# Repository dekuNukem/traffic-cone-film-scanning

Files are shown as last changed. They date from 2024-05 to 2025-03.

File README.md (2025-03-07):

# Traffic-Cone Film Scanning: High-Quality Digitization on the Cheap

[Discord](https://discord.gg/wB9mKjD2Cn) | [Table of Contents](#Table-of-Contents)

-----

Analog photography is having a resurgence, many people are shooting film again.

To view and share the photos, they need to be digitized.

Scanning using a digital camera is popular, but a conventional setup can cost [hundreds of dollars](images/dollaz.png).

TCFS is a low-cost 3D-printable alternative that produces high-quality results at a fraction of the price.

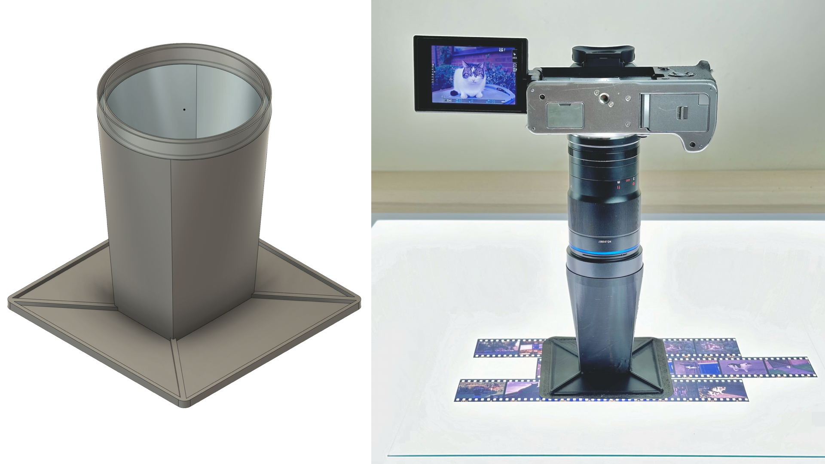
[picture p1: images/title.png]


## How It Works

* Print a cone
* Attach to macro lens
* Film under glass
* Camera point straight down.
* Focus and shoot!

## Advantages

* **Low-cost**: $1 in filaments.
* **Easy setup**:
	* No tripods/copystands
	* Fixed distance, no calibration.
* **Fully Enclosed**
	* No stray lights
	* No reflection
* **Multi-format**: Subminiature, 35mm, 120, sprockets, and more!
* **Open-source**
	* Customizable parametric design
	* CCBY4.0 license.

## Table of Contents

- [Sample Scans](#samples)
- [Items Needed](#sounds-great-im-in)
- [Cone Preparation](#cone-preparation)
- [Cone Assembly](#cone-assembly)
- [Scanning Preparation](#scanning-preparation)
- [Scanning Procedures](#scanning-procedures)
- [About Newton Rings](#a-word-on-newton-rings)
- [Feedback Wanted!](#howd-it-go)
- [License Note](#license-note)

## Samples

Fuji XT4 + Laowa 65mm f/2.8

35mm



35mm Sprocket



6x6 Negative



6x6 Slide

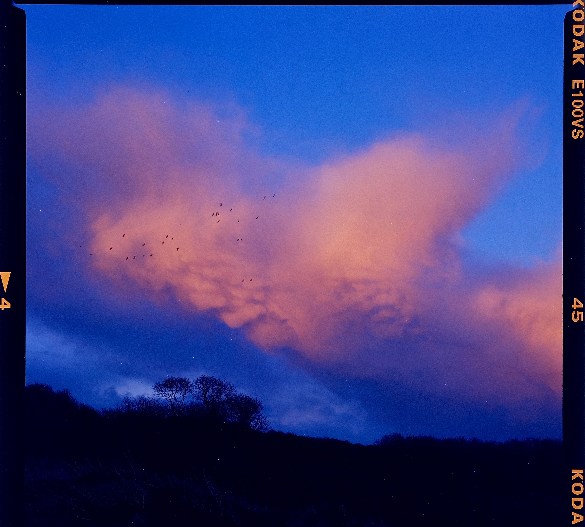
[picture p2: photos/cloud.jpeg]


[More full-size samples here](https://github.com/dekuNukem/traffic-cone-film-scanning/tree/master/sample_scans)

## So What's the Catch?

While TCFS can achieve excellent results, there are a few things to keep in mind.

#### DIY Involved

* You need to be a bit handy.
* Wire a plug, use a caliper, etc. Nothing too crazy.

#### Obtaining a Cone

* One cone per film format.
* For lowest cost, print your own. Basic 3D printing experience needed.

#### No Magic Bullet

* TCFS can be as good as any expensive DSLR/mirrorless setup when done properly.
	* Able to get the most out of 35mm & smaller
	* Also great with medium format
	* But likely won't extract all its resolution
* For utmost quality, wet mounting/drum scans are still hard to beat.
* Main advantage is excellent scans at much lower cost, easy setup, and faster speed.

## Sounds Great, I'm In!

Let's get started! The setup involves:

* Digital Camera
* Macro Lens
* Lens Hood
* Light Table
* Flat Glass
* The Cone

## Digital Camera

Obviously, you need one of those.

Any DSLR or Mirrorless made in the past decade should be more than good enough.

No need for latest and greatest. APS-C sensor is plenty.

A **swivel / tilt screen** would be nice to have, makes checking focus easier.

## Macro Lens

The quality of the scan depend largely on the lens.

For best results, I recommend:

* A proper **macro lens**
* With **internal focusing** (front element doesn't move)

---------

**Magnification Ratio** is important:

* A 1:1 (1x) ratio means the lens can project the **actual size of the subject** onto the sensor
* At 2:1 (2x), the subject can be projected **twice as big** on the sensor
* Therefore, a decent MR is useful for smaller formats (35mm and under).

-------

You can drop 4 figures on a flagship first-party lens, but for film scanning it's a bit overkill.

A popular choice is [Laowa 65mm f/2.8 2x Ultra Macro APO](https://www.venuslens.net/product/laowa-65mm-f-2-8-2x-ultra-macro-apo/):

* 2x MR
* Superb image quality
* Around $330

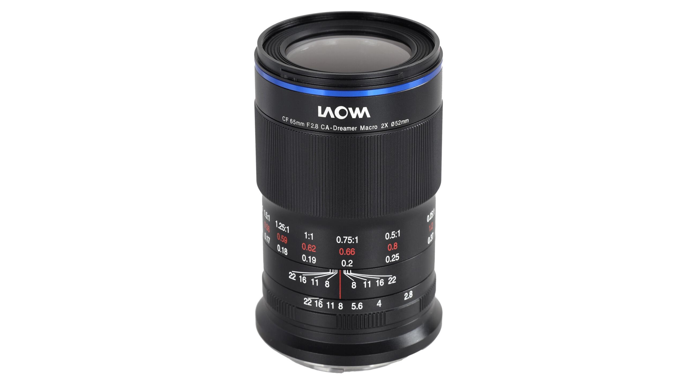
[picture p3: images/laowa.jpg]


Another one is [7Artisans 60mm f/2.8 Mark II](https://7artisans.store/products/7artisans-60mm-f2-8-mark-ii-macro-lens-for-sony-e-fuji-fx-canon-eos-m-olympus-m43-nikon-z-mirrorless-cameras):

* 1x MR
* Excellent image quality
* Around $160

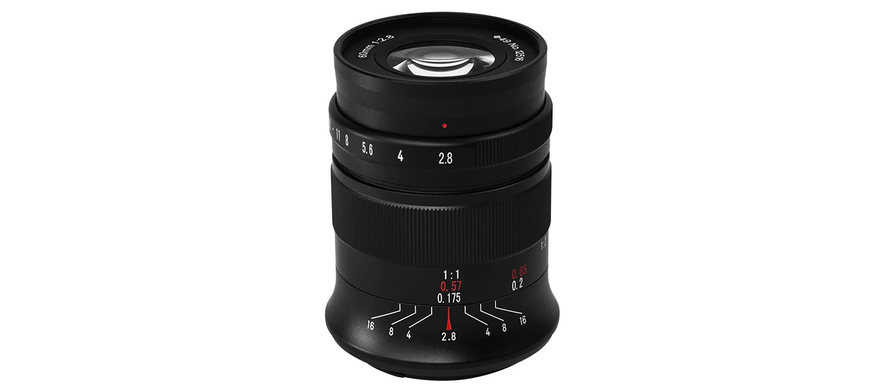
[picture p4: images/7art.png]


I have both, and personally I prefer the Laowa:

* Inboard aperture ring, less likely to bump into during focusing.

* Smoother focus ring, allowing finer adjustments.

* Extra magnification handy for subminiature formats (110, 126, half-frame, etc)

Anyway, can't go wrong with either. Available cheaper on aliexpress.

-----------------

Many **vintage lenses** are good candidates too, and can be even cheaper.

However, you need to do your own homework. Search `Film scan macro lens` on google.

[This article has a fairly extensive tier list](https://web.archive.org/web/20240206003914/https://www.pixl-latr.com/how-good-a-macro-lens-do-you-really-need-for-dslr-mirrorless-camera-scanning/).

## Lens Hood

We need a lens hood to attach the cone to.

* **Circular** shape
* **Fully enclosed**
* One-piece **metal** (not collapsible)
* Not too tall

Just get the cheapest from ebay or aliexpress, they are all the same. 

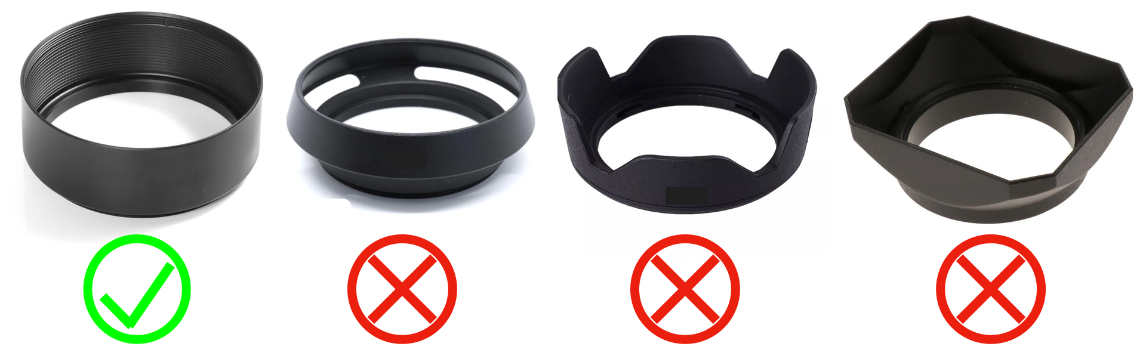
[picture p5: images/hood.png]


## Light Table

A bright and even light source is needed to illuminate the film from behind.

You can spend a lot on the usual suspects that sponsor Youtube videos.

Instead, I recommend getting a **LED Light Panel** for office ceilings.

They are a lot cheaper, and give you a massive area to work with.

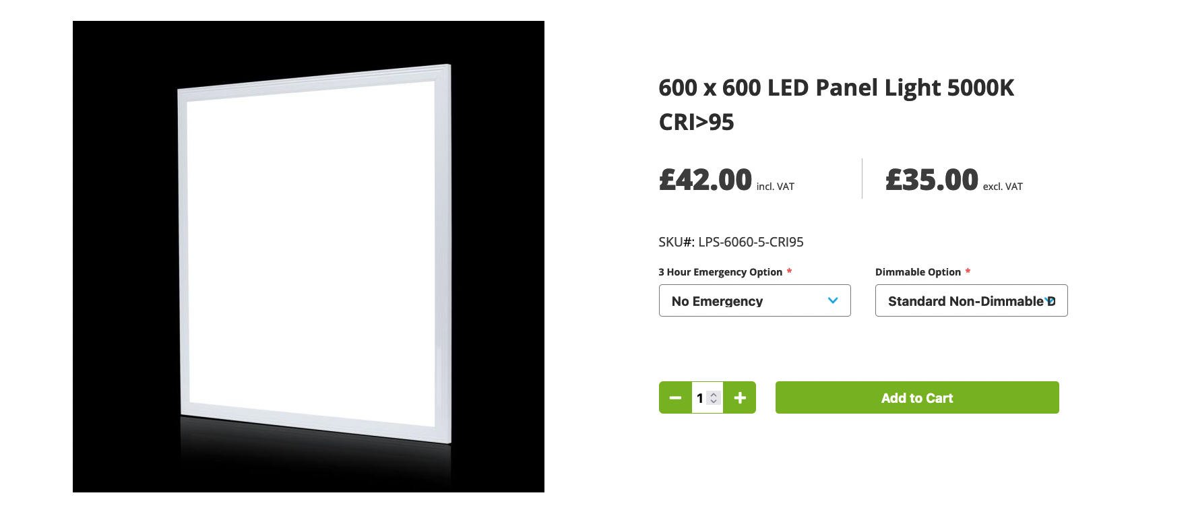
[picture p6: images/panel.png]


* Make sure it's **High-CRI** (>95)
* Neutral color temperature (**Around 5000K**)
* Flat matte surface finish (pretty sure they all are)
* Standard size is 600x600mm / 24x24in 
* Smaller ones available, but I like it big!

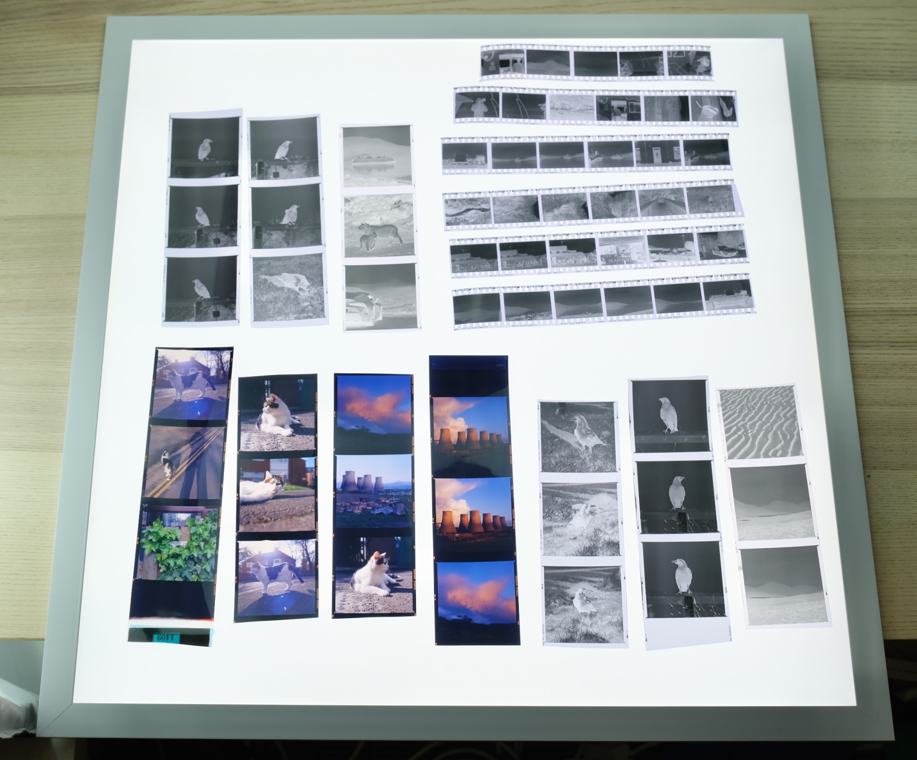
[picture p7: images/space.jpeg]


The LED panel comes with a power adapter. You need to wire a plug to it.

⚠️ ⚡ Mains voltage is involved! 

⚠️ ⚡ Make sure you know what you're doing!

⚠️ ⚡ Look up how to wire a plug in your country.

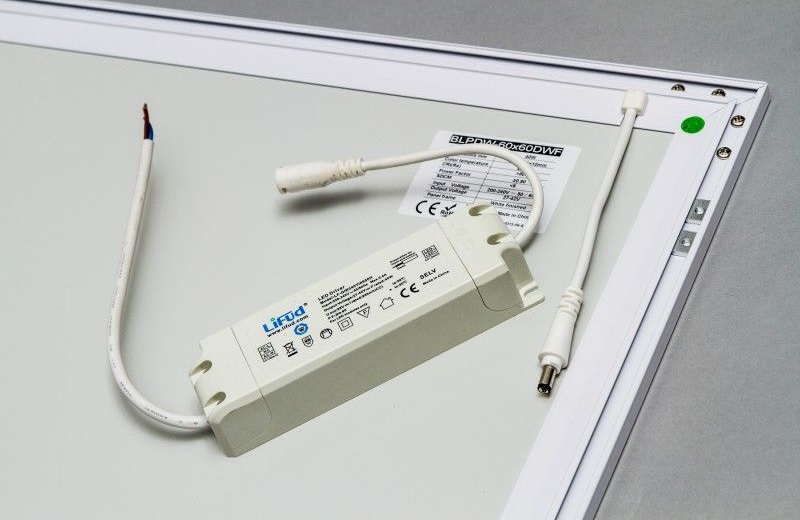
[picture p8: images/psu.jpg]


Generally:

* Brown is **LIVE**
* Blue is **NEUTRAL**
* Green/Yellow is **EARTH**

Inexpensive lever-actuated connectors like WAGO 221 is very useful.

If you do use them, make sure to have **strain relief**, so it won't accidentally pull out and expose the live wire.

Just a simple knot should be fine. When tugged, it will pull the knot tighter instead of ripping out the wires.

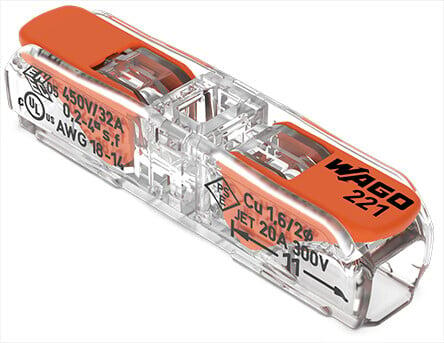
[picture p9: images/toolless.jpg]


You can use a regular plug and turn it on/off at the power strip, or an inline switch to be extra fancy.

Remember to **twist-lock** the output jack!

## Flat Glass

We need a piece of glass to hold the film flat on the light table.

* Around 2mm thickness
* At least 8x10 in size, mine is 11x14.
* Make sure it's **glass** NOT acrylic
* I got mine from a picture frame at a thrift store

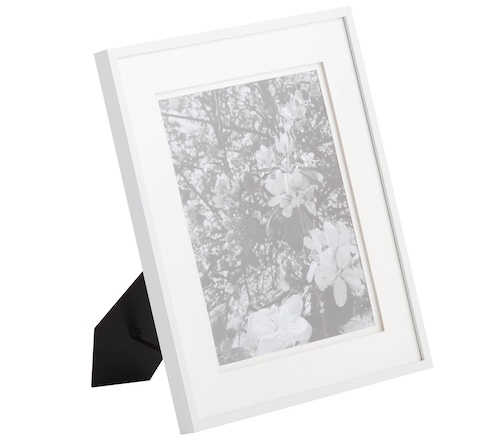
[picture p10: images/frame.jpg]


#### But what about newton rings???????

I'll talk about it later, but just know it won't be a big problem.

I suggest start with cheap plain glass, you can always upgrade to ANR glass later.

## Cone Preparation

For best results, the cone should be customized to your specific lens.

### I have the lens below!

* `Laowa 65mm f/2.8 2x Ultra Macro APO`
* `7Artisans 60mm f/2.8 MK II`

Great! Download a file and go to the next section.

* [35mm Full Frame](3d_models/laowa_7art_35mm_fullframe.stl?raw=true)
* [35mm Sprocket](3d_models/laowa_7art_35mm_sprocket_6x6.stl?raw=true) (using 120 adaptor on 6x6 camera)
* [645](3d_models/laowa_7art_645.stl?raw=true)
* [6x6](3d_models/laowa_7art_6x6.stl?raw=true)
* [6x7](3d_models/laowa_7art_6x7.stl?raw=true)
* [6x9](3d_models/laowa_7art_6x9.stl?raw=true)

### I'm using my own lens / I want to customize!

[Click me to learn how to customize your cone.](cone_customization.md)

## Printing the Cone

Now you have the model, time to print it!

If you don't have a 3D printer, try local library, makerspace, or online printing services.

* Use **opaque black** filament, PLA works just fine.
* Around 10-20% infill
* Very simple design, turn up the speed if you want.

2 hours later, voilà:

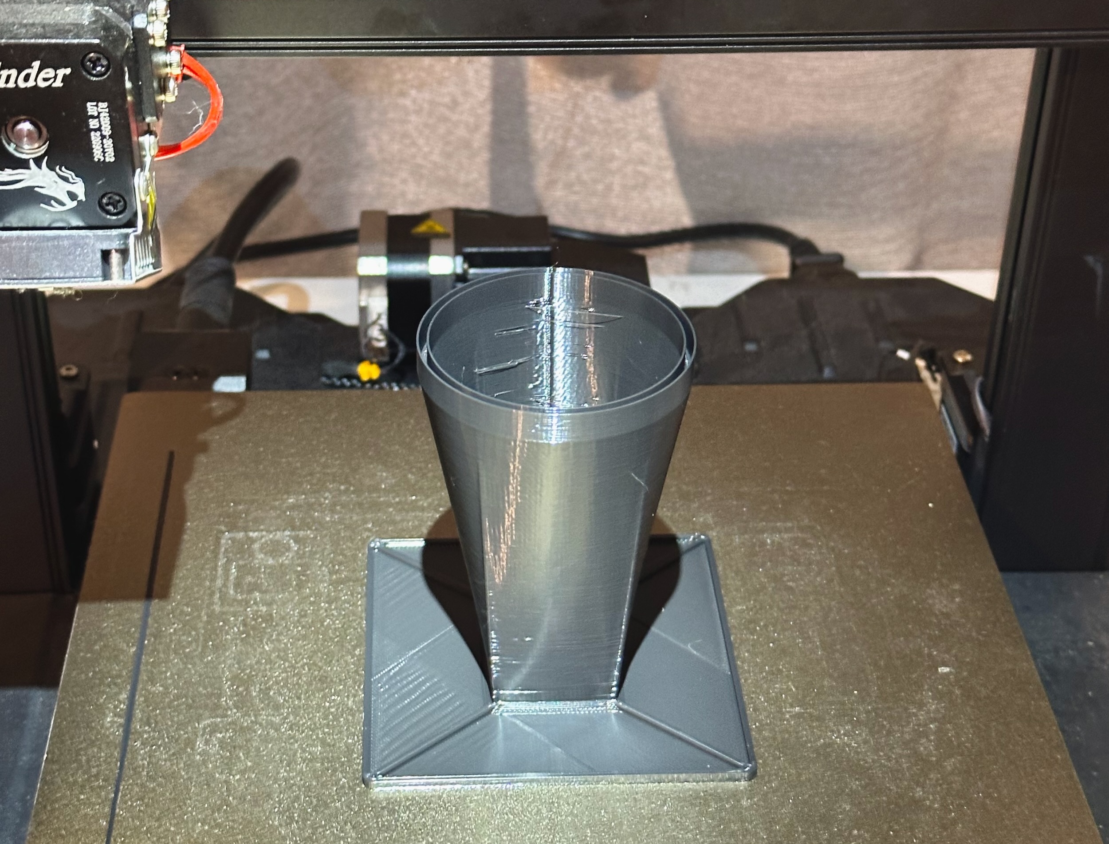
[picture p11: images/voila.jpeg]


* Wait for the bed to cool down before removing.
* Double check the base is **completely flat**.
* It **must not** wobble when placed on flat surface.
* If warped, improve bed adhesion. Re-level, hairspray, raft, etc.

## Cone Assembly

* First, remove any filament whiskers/strands **near the film gate**.

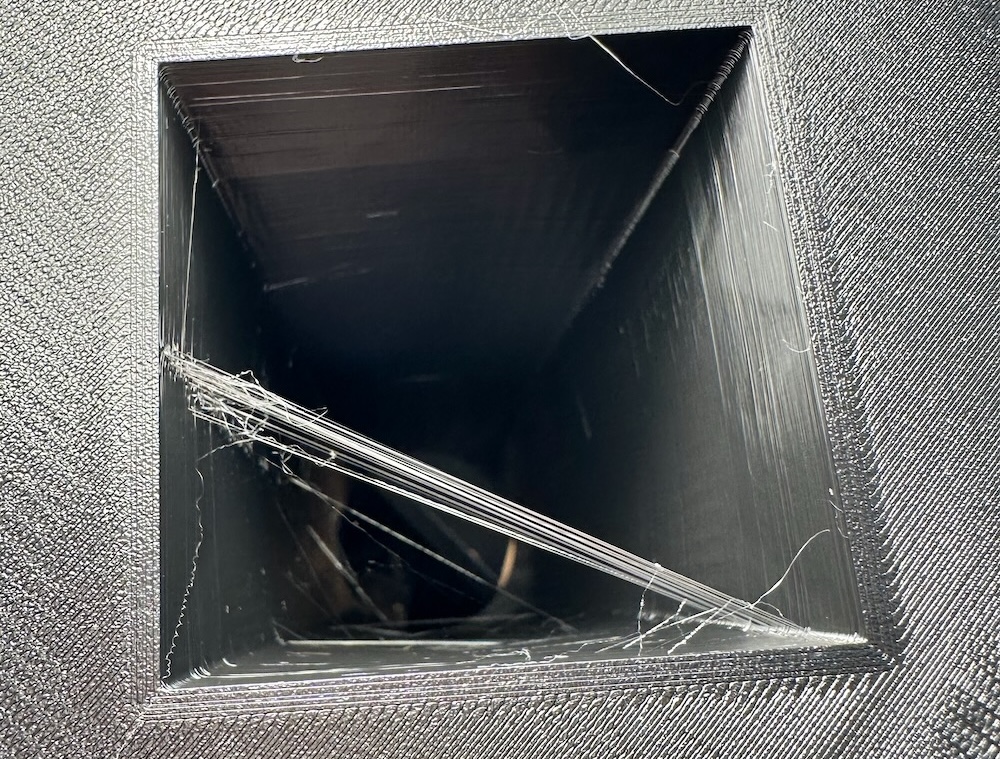
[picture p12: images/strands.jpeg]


* Whiskers higher up won't show up, leave them if you want.

-----

* Put the cone on the light table
* Attach the lens hood, moderately tight

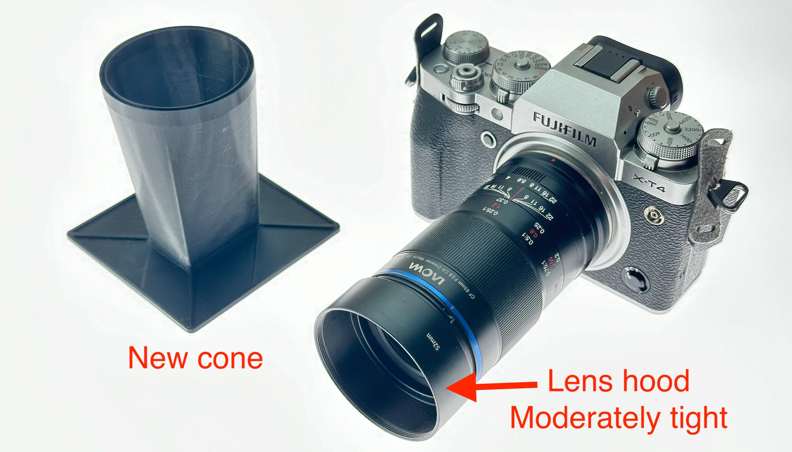
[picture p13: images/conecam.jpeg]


* Hover the camera just over the cone, barely touching.
* Adjust focus and position.
* Until the film gate is **parallel** with camera frame

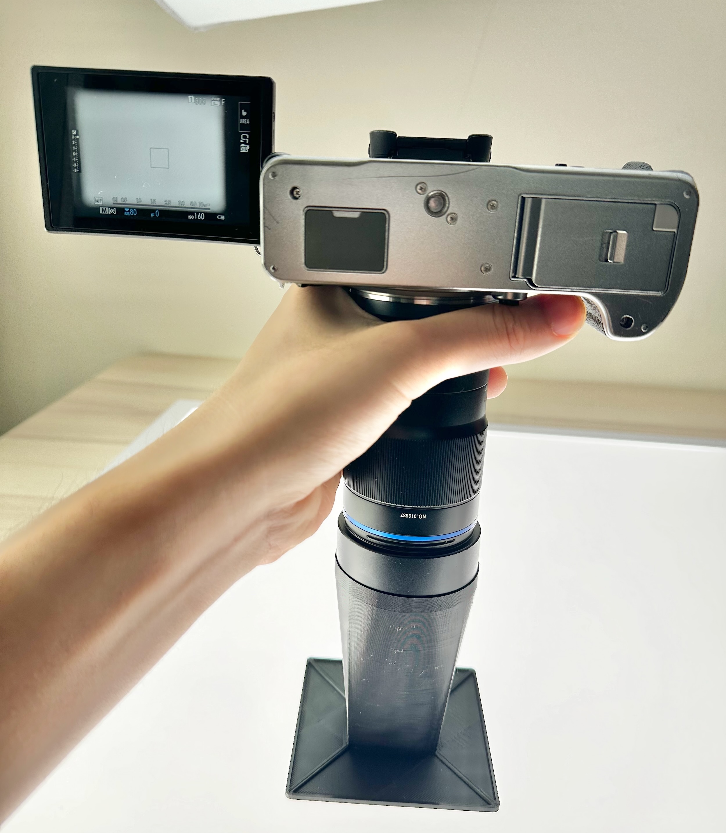
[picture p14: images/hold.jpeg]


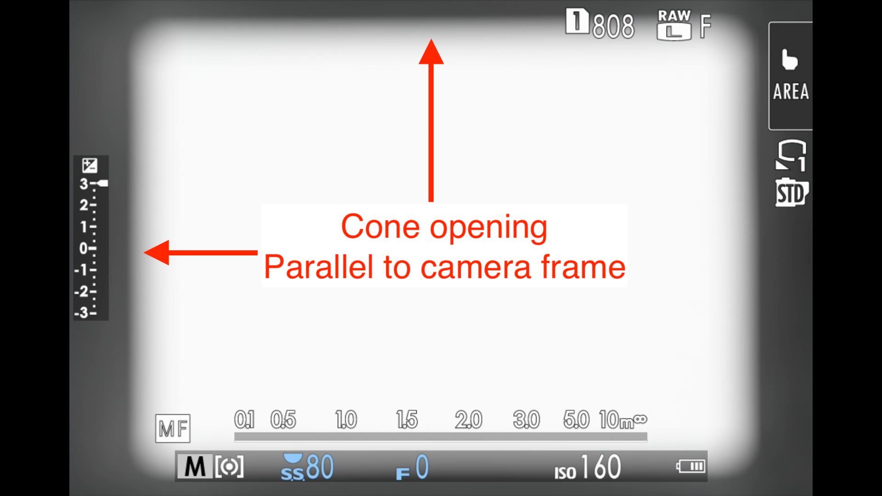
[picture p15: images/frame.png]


* Mark the position of the cone with paint marker, or a scratch mark.

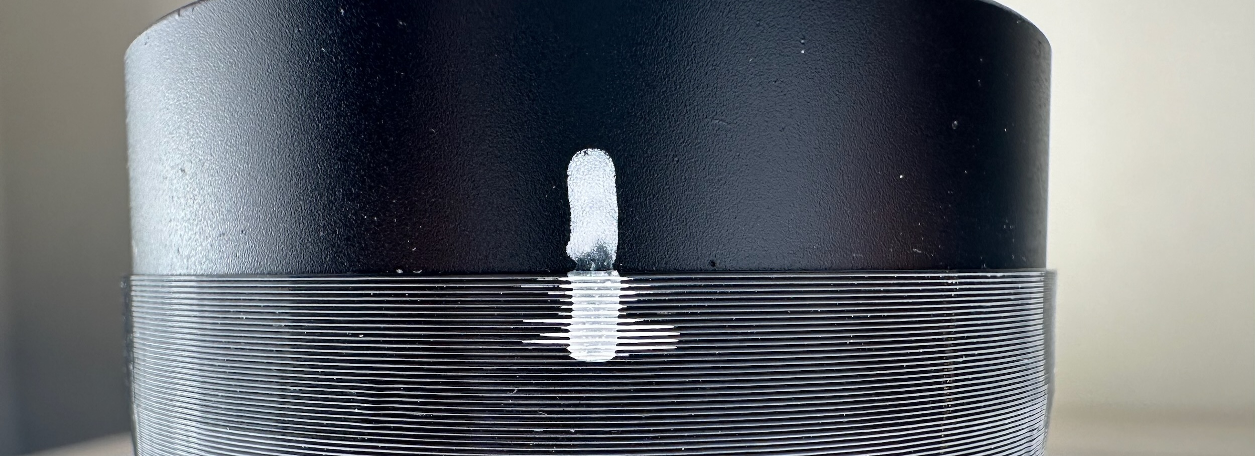
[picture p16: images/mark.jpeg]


* Unscrew the lens hood
* Put the cone on a flat surface (**NOT LIGHT TABLE**)
* Ensure the mark is still aligned
* Push all the way in
* Make sure it **bottoms out** and **flat and level**

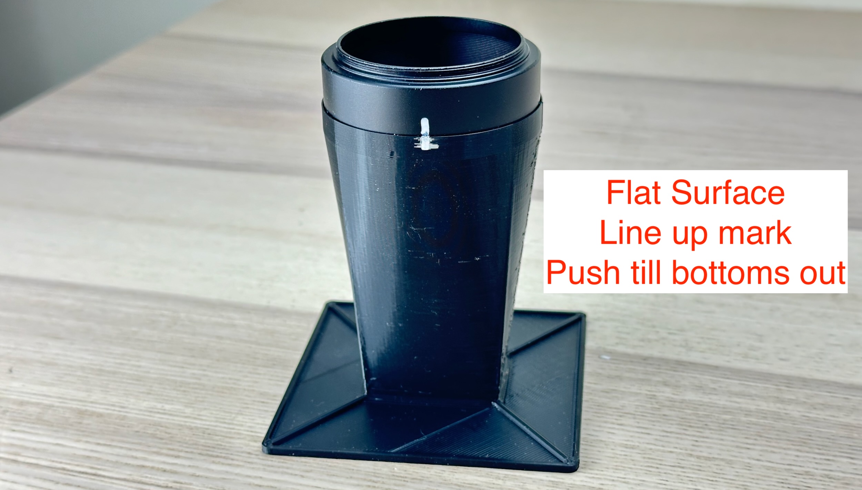
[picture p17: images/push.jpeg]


The cone should grip the lens hood tightly. 

If too loose, use some duct tape, or print a new one.

## Scanning Preparation

The cone is ready! Before start scanning, we need to set up a few things.

### Light Panel

Put the light table on a flat surface.

If the power jack sticks out, let it hang off the edge. Double check it is **twist-locked**.

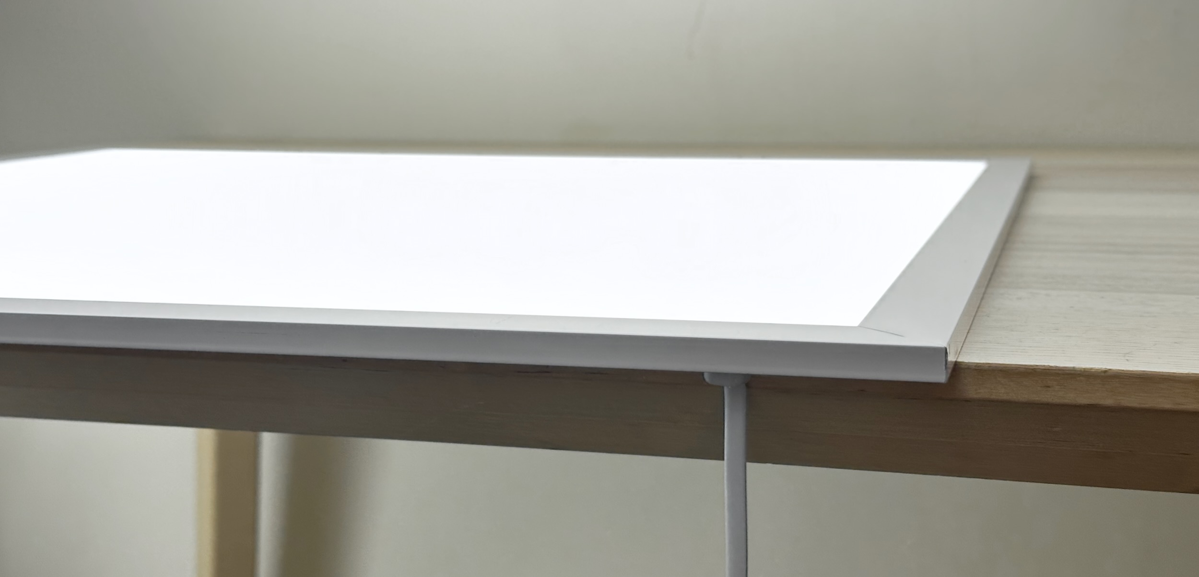
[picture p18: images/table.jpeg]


The panel should be flat and not wobble.

### White Balance

Set a **custom white balance** to your light table.

Usually involves taking a picture of the blank table. Refer to user manual.

### RAW Output

Select RAW output format for best quality, needed for most converting software.

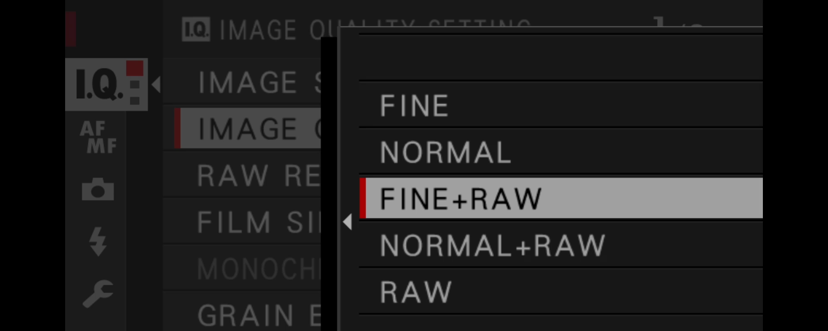
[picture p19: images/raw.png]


### Focus Assist

We are going to manually focus on the negative.

**Focus peaking** is essential to ensure a sharp scan.

Make sure it's on.

Color blue has good contrast against orange negatives.

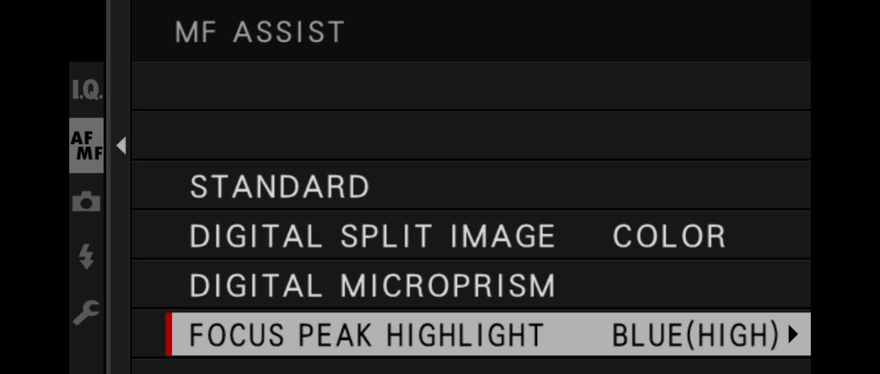
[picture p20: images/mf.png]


### Dust Management

We have a few potential surfaces for dust, so it is crucial to be as clean as possible.

#### WEAR GLOVES

* **DO NOT** touch film / glass with bare hands!
* I use disposable gloves, make sure its **powder-free**.
* Reusable gloves works too, but may shed lint.

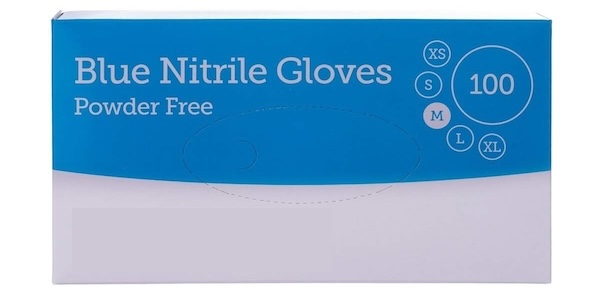
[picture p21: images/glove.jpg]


#### Wipe-down

* Before a scanning session, wipe clean the light table and glass (both sides).
* I use **Chamois Leather**. They are inexpensive, but make sure it's real (as in from an animal).
* Microfibre cloths works too, but I find them shed a lot of lint. 

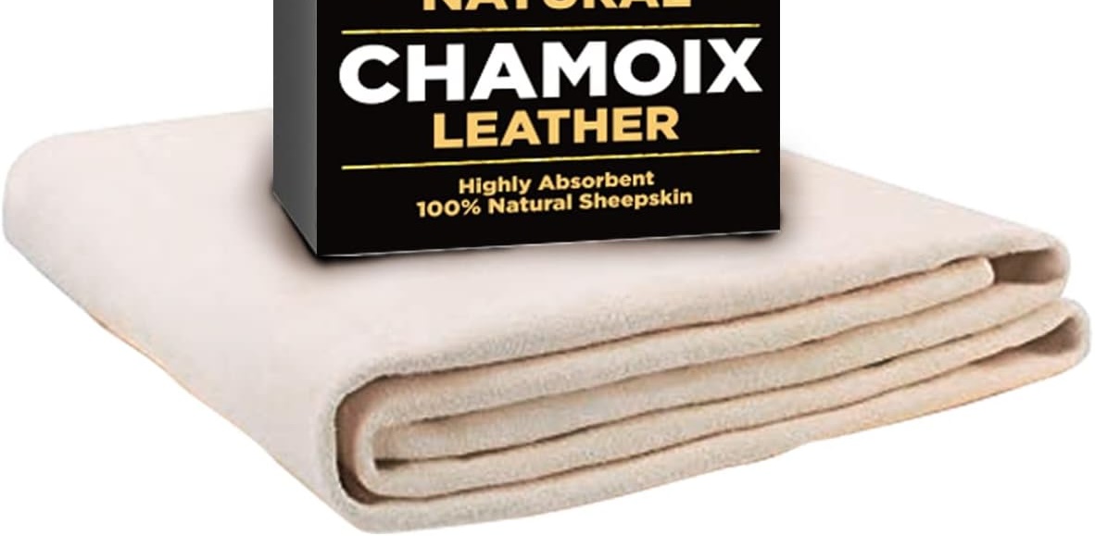
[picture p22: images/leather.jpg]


## Scanning Procedures

Finally! Let's start.

* **Wear gloves**

* Wipe down the glass and light table with chamois leather

* Place film strips **emulsion side up**

	* The side that **curls up**

	* Picture/edge markings should **look mirrored**

	* Place near the **CENTER** of the light table

	* Can be the entire roll if your glass is big enough

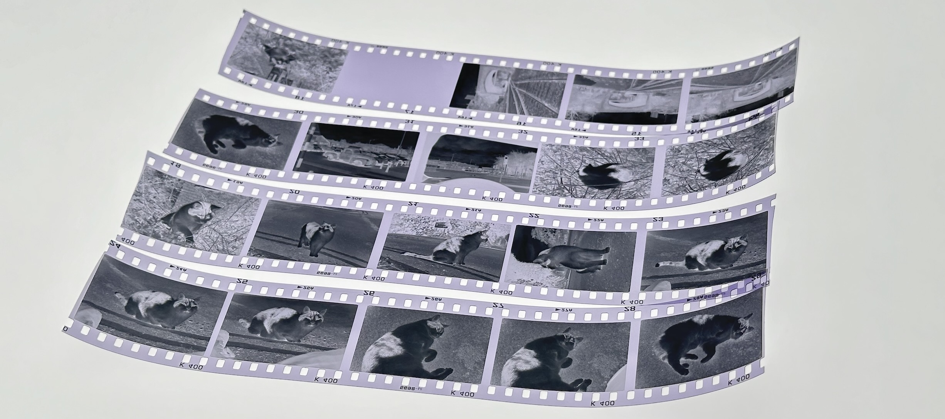
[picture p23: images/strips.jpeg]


* Glass on top. Ensure **no overlapping**

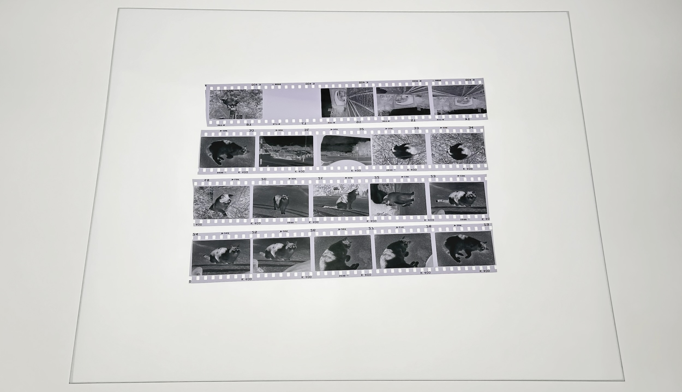
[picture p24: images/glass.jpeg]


* Double check camera settings:
	* Custom white balance
	* RAW output
	* Manual focus w/ **focus peaking**
	* Lowest ISO

* Set aperture to f/8
	* Too small aperture (large f number) would soften the image due to diffraction 
	* Too large aperture (small f number) makes it difficult to focus
	* f/8 is just about right

* Use **center-weighted autoexposure**. Or fully manual if you want.

* Using a **remote release** is strongly recommended to reduce vibration and speed up the process

	* The type with 2.5mm jack are all the same, just get the cheapest one
	* You camera might also support wireless remote or phone app

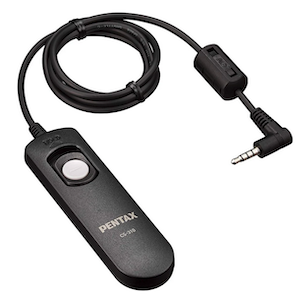
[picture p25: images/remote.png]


---------

* Attach cone to the camera

* Place over a negative

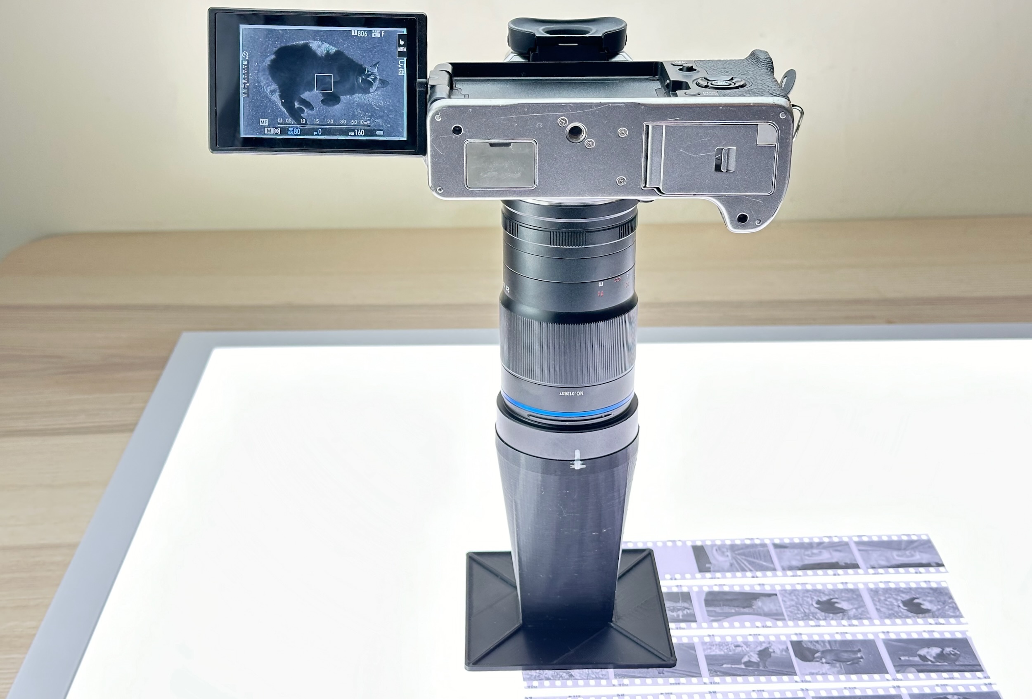
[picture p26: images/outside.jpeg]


* Line up the picture

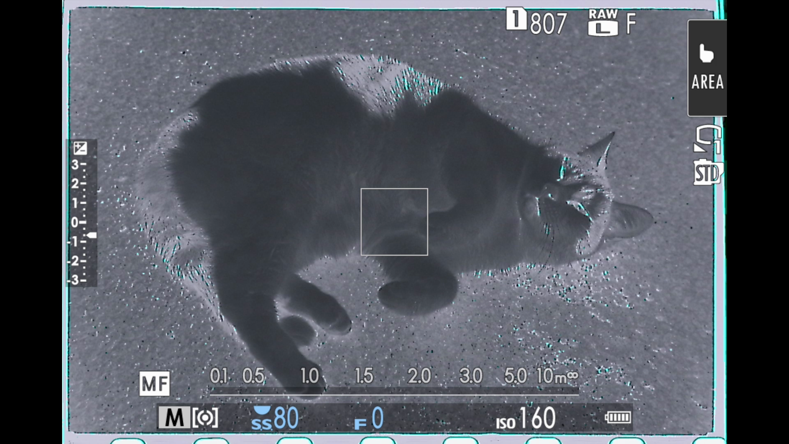
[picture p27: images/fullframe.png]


* Enter **magnified view** with focus peaking

* On Fuji X-T4, push the rear thumbwheel. Look up how to do it on yours.

* Find a sharp area on the negative

* Adjust focus ring. **Try not to apply too much downward pressure**.

* Until you achieve **maximum amount of "sparkles"**



* The tolerance is razor-thin! Tiny amount of movement is all you need.

-----

Now we are in focus!

From now on, avoid touching the camera as much as possible!

* Take a photo using remote release / remote app / self timer.

* Slide the cone around the glass for each frame

* Grab the neck of the cone, not the lens, to avoid accidentally knocking out focus.

--------

It should stay in focus for the whole session.

If you're paranoid, re-focus every time you lift the glass to put new negative in.

Definitely re-focus if left overnight. Temperature changes can cause focus drift.

## Post-Processing

Now we have high-quality scans in RAW format.

Additional processing is needed to get the final result.

We need to **invert**, **mirror**, and adjust the color of the photo.



There are a lot of guides online, so I'm not going to cover the details.

For black and white, I find it doable manually. But for color, it's much easier with a dedicated software.

Popular ones include:

* [Negative Lab Pro](https://www.negativelabpro.com/) (paid, requires Adobe Lightroom)

* [Grain2Pixel](https://grain2pixel.com) (free, requires Adobe Photoshop)

* [Darktable + Negadoctor](https://docs.darktable.org/usermanual/3.8/en/module-reference/processing-modules/negadoctor/) (free, but very fiddly last time I tried)

* [Filmomat SmartConvert](https://www.filmomat.eu/smartconvert) (paid, standalone)

-------

Personally, I use Filmomat SmartConvert to invert the negative, and macOS photos app for minor adjustments.

Zeiss Ikon Contessa 35 (Folding, 533/24), c. 1952.



Amazing how good it looks despite being over 70 years old!

## Key Points

As always, you'll get quicker with time.

To recap, those are the most important points to remember:

* **Wear gloves**
* Chamois leather wipe-down
* Emulsion side up
* White balance / RAW output / Low ISO
* f/8
* Nail the focus
* Use remote release

## A Word on Newton Rings

Newton rings are circular interference patterns caused by close proximity of two smooth surfaces.

They often appear where film touches smooth glass:

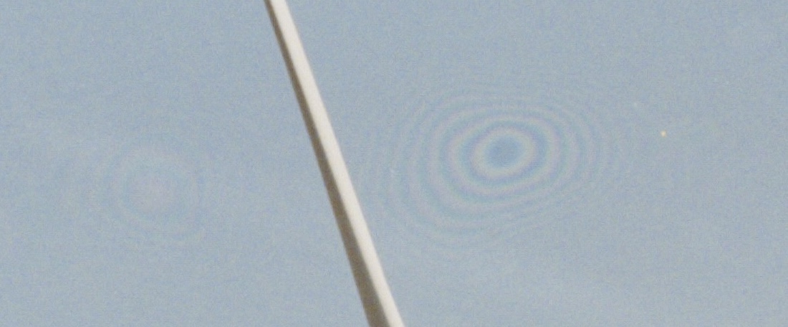
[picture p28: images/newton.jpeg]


Curiously, from my experience, it almost never occurs with TCFS, even with plain glass.

I have a theory:

* We scan with emulsion side up, which is typically more matte.
* Film are also placed near the center of the light table.
* Due to its size, there might be a minuscule amount of curvature on its surface.
* Such that the film are not squished right against the glass!

#### 😡 OMG that means the film is NOT FLAT!!1!🤬y didnt u tell me eariler what a waste of time!! 

* The curvature (if any) is absolutely tiny, especially with the camera pushing down.
* Such curvature is well within the depth of field of your digital camera.
	* For 35mm, you have [2.6mm DoF](images/dof35mm.png).
	* That's the thickness of 4 credit cards, or 20 times thicker than the film itself!
	* You'll definitely notice if it's that much.
	* For 120, [DoF is 7.6mm](images/dof120.png). More than a quarter inch!

---------

* I would suggest:
	* Follow the instructions
	* Focus properly on the negative
	* Look at the result yourself and decide. The proof is in the pudding. 
* Feel free to examine my [full-size samples](https://github.com/dekuNukem/traffic-cone-film-scanning/tree/master/sample_scans).
* Finally, if it really bothers you, you can always get some ANR glass.
* [Useful discussion here](https://old.reddit.com/r/AnalogCommunity/comments/pex269/anr_glass_alternative_using_etched_frame_glass/).

## How'd It Go?

That's it! If you read this far, hopefully you have already made some scans, or at least interested in trying!

I would love to hear about your experience, good or bad, as well as any comments, questions, and suggestions, in order to improve this process.

Get in touch [via Discord](https://discord.gg/wB9mKjD2Cn), or email: dekuNukem&gmail.com!

## License Note

The **scanning cone** design is under [CC BY 4.0 License](https://creativecommons.org/licenses/by/4.0/deed.en)

You can:

* Share, modify, remix, and redistribute the material, even commercially.
* **AS LONG AS** you give appropriate credit to me (dekuNukem) and [the project page](https://github.com/dekuNukem/traffic-cone-film-scanning).

The sample photos are **NOT** under CC BY 4.0 and are all rights reserved.

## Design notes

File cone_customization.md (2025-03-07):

# Traffic-Cone Film Scanning: Customization Guide

[Main Page](README.md) | [Discord](https://discord.gg/wB9mKjD2Cn)

----------

This guide shows you how to customize the cone to **your particular lens and film size**.

## Install Autodesk Fusion

Autodesk Fusion is a popular 3D CAD software.

We're going to install the free version, customize the traffic cone, and print the result.

------

Go to this link:

https://www.autodesk.com/products/fusion-360/personal

Create a free personal-use account, download, and install.

* Launch Autodesk Fusion
* Click through until you see the main screen
* File icon -> Open...

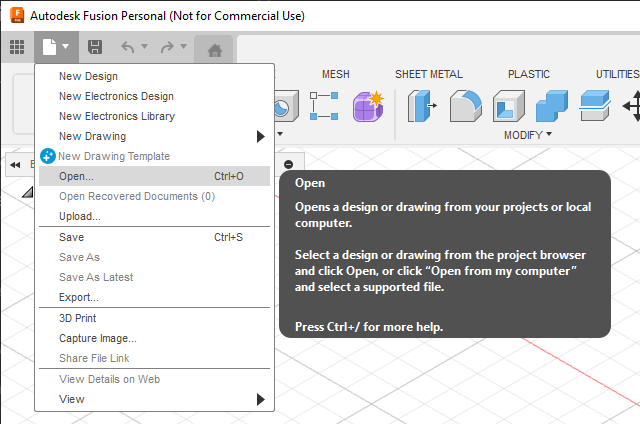
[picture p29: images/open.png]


* Select `Open from my computer...`

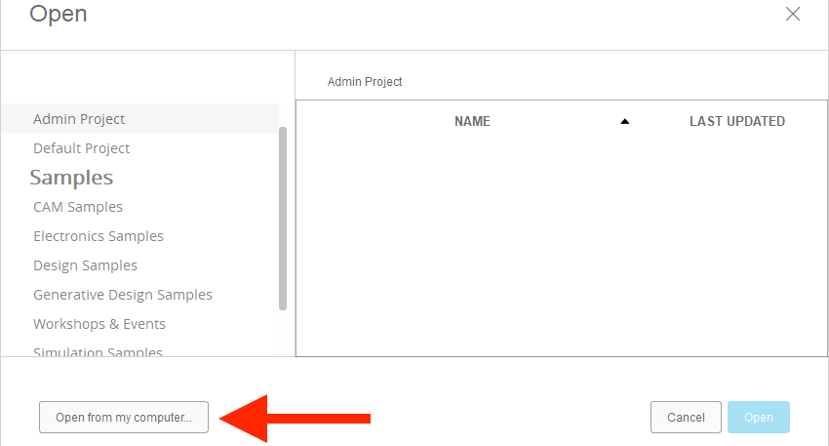
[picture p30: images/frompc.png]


* Download the [template cone](https://github.com/dekuNukem/traffic-cone-film-scanning/raw/master/3d_models/cone_template.f3d) and select it.
* Feel free to drag the viewcube to look around.
* Click its edge/corner/face to snap to view point.

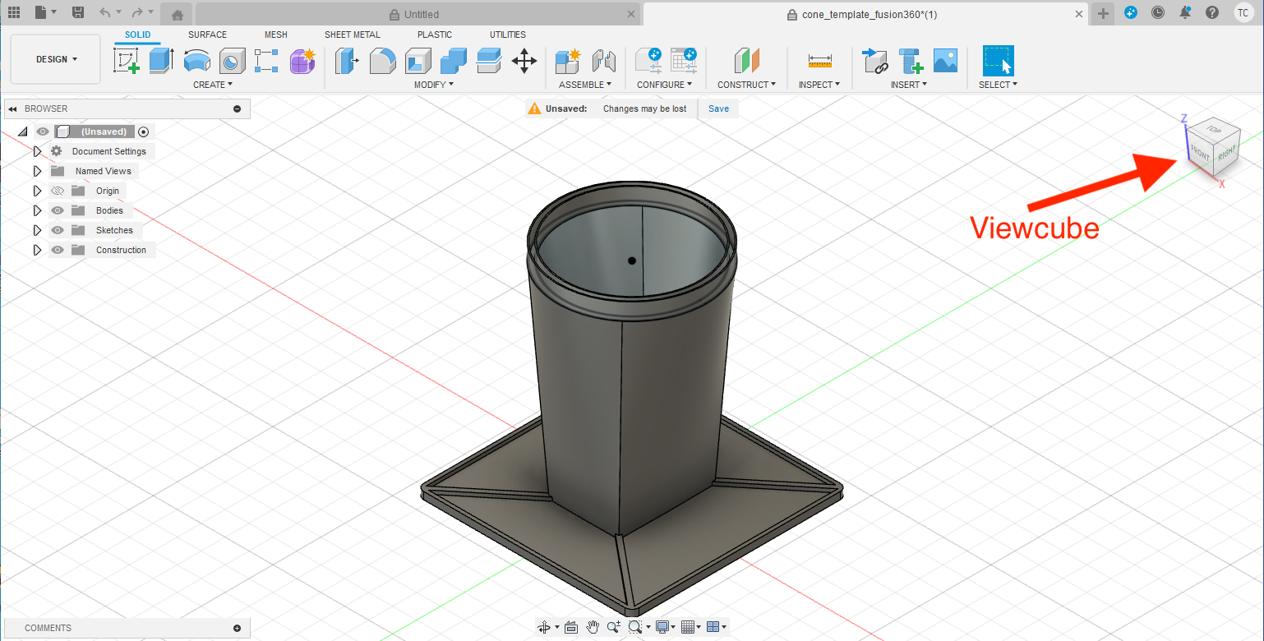
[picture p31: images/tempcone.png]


* Click on `MODIFY` menu
* Select `Change Parameters`

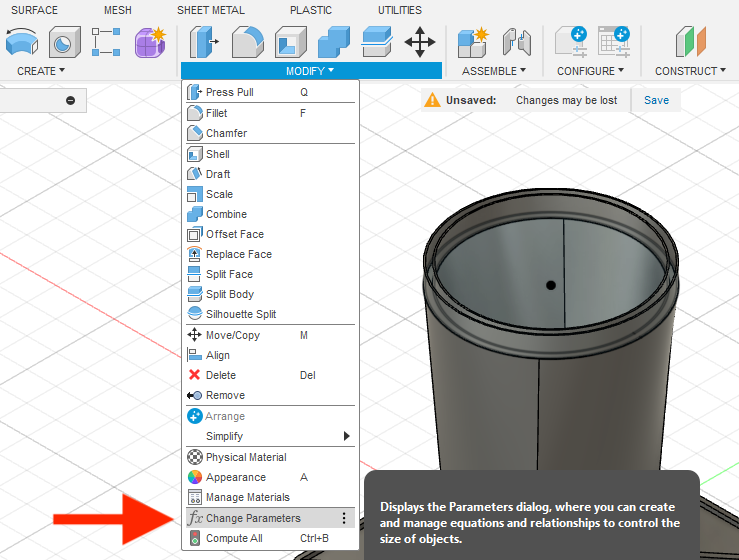
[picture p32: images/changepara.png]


* Here you can see all the parameters for this cone.

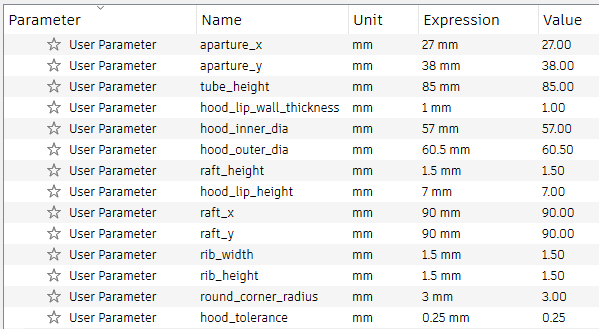
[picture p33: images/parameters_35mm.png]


* Don't touch anything yet!
* Changing the values here will alter how the cone looks. 
* But first, we need to do some measurements.

## Measurements

In this example, I want to make a cone for **645** format with `Laowa 65mm f/2.8` and `Fuji X-T4`.

* Light panel flat on table, turn on.
* Film under glass
* Don't worry about dust yet, it's only for measurement.
* Install lens hood

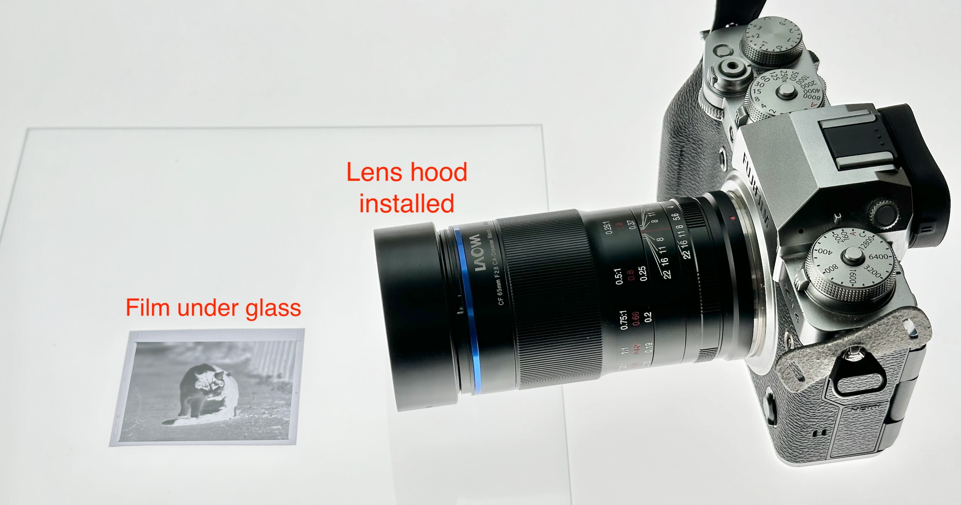
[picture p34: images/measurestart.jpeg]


* Camera on
* Point straight down
* As best as you can, adjust height and focus, until the photo:
	* Fills most of the frame, AND
	* In focus
* Leave a little space near the edge to make alignment easier 

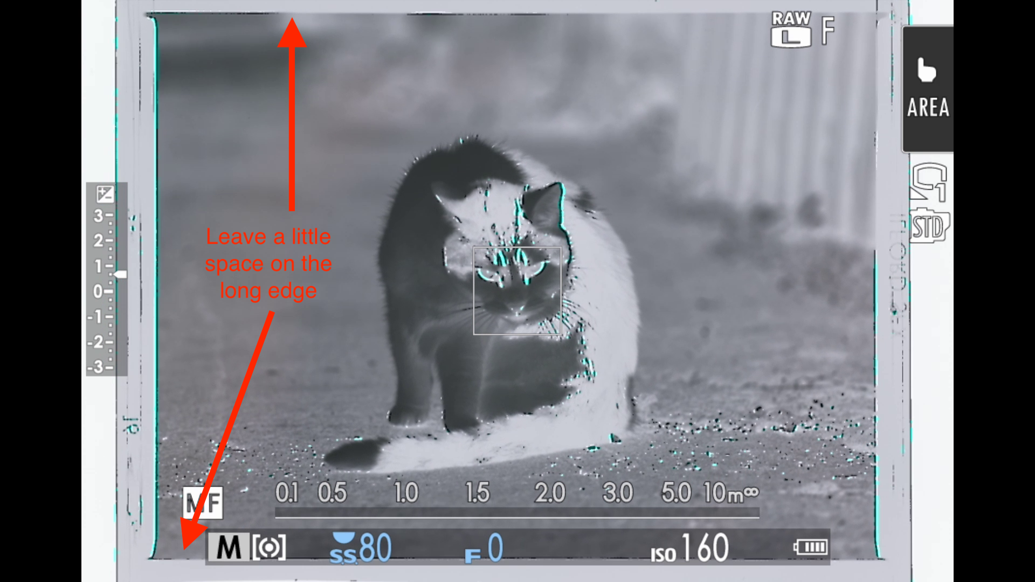
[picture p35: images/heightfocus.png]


* Hold steady
* Measure the distance from **`glass surface`** to **`lip of lens hood`** in **mm**

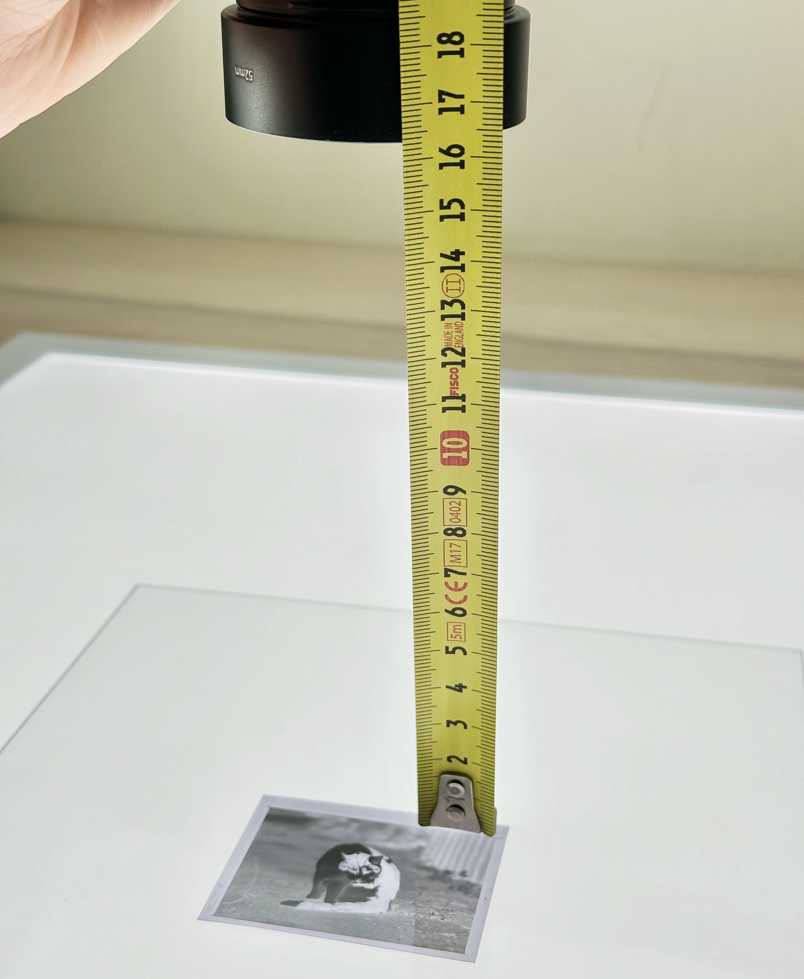
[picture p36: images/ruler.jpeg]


This will be the **height** of the cone.

Around 16cm, or 160mm, in this case.

Write it down.

----

Next, use a caliper, measure the **inner** and **outer diameter** of the **outward facing rim** of the lens hood in **mm**.

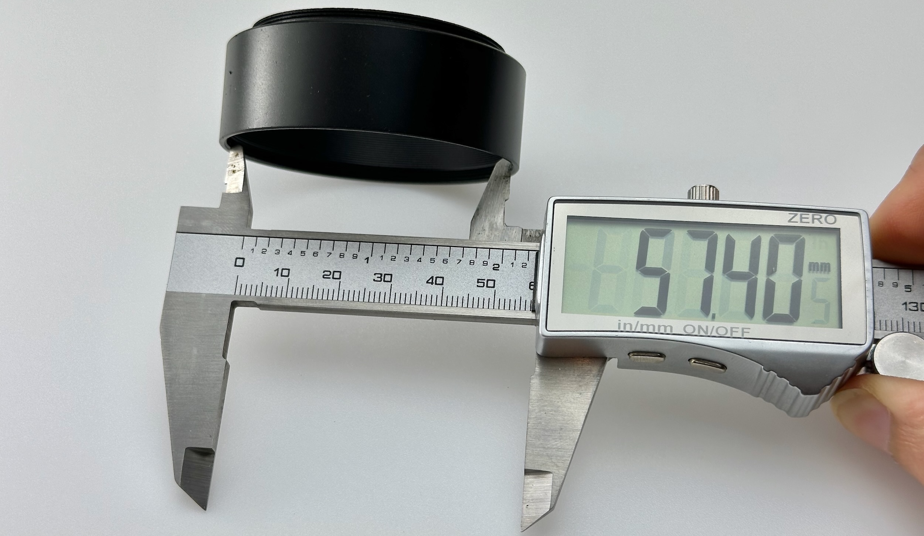
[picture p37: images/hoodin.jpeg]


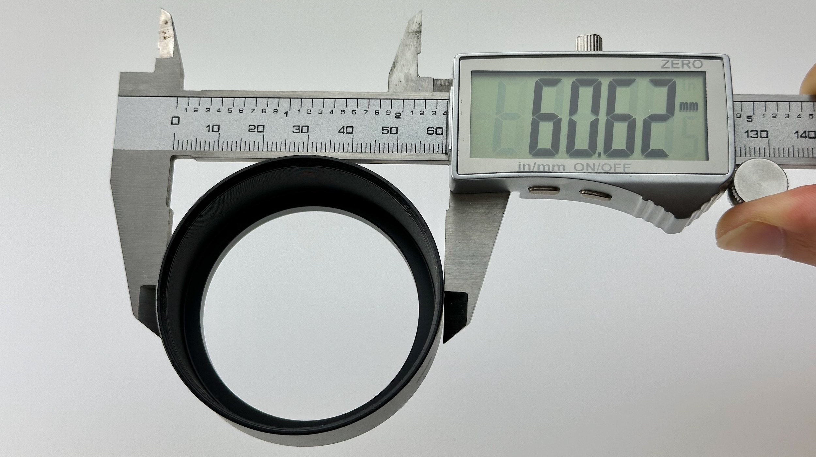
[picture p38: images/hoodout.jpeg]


Write those down as well.

That's it! We're done.

## Parameter Adjustment

Back in Autodesk Fusion. We can now put in the values we just measured.

Click the **number in Expression column** to change the value.

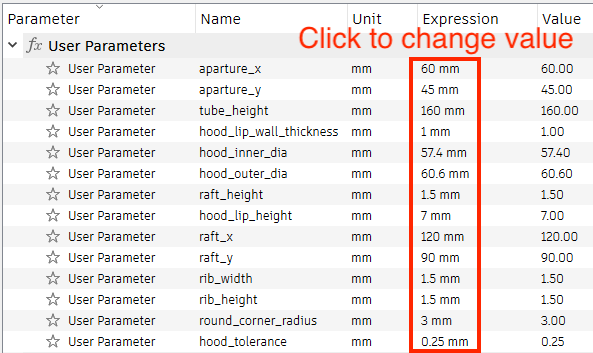
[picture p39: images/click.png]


Usually, the following values need to be changed:

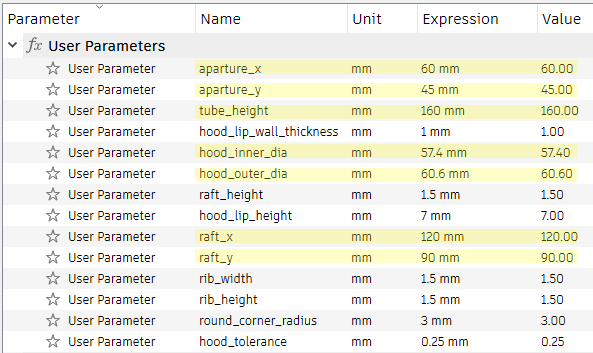
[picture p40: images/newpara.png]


#### `aperture_x` and `aperture_y`

* Size of the scanning window.
* 24×36mm for 135, 60x45mm for 645, 60x90mm for 6x9, etc.
* Add extra 1mm for margin of error if you want.

#### `tube_height`

* Height of the cone you measured, in **mm**.

#### `hood_inner_dia` and `hood_outer_dia`

* Lens hood diameters you just measured
* Type in exactly **as-is**

#### `raft_x` and `raft_y`

* Size of the "base" of the cone
* Default is 90x90mm, works pretty well.
* Increase slightly for larger formats.

No need to change anything else.

---------

As you type in new values, the cone changes shape accordingly.

It is now much taller:

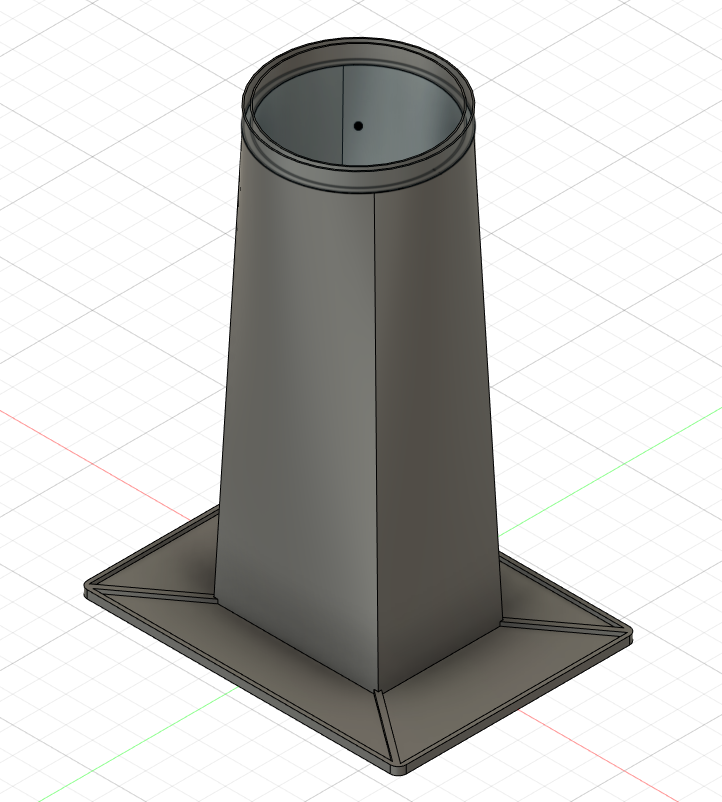
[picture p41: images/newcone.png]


We can now 3D print the new cone!

* File icon -> 3D Print 

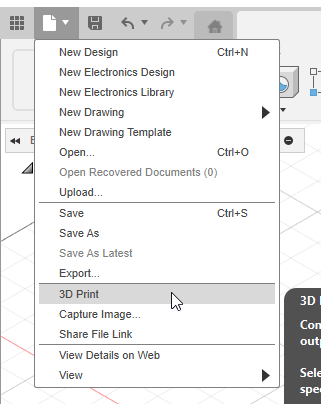
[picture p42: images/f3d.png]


* Click on the 3D model
* Export STL file, or send directly to a slicer.

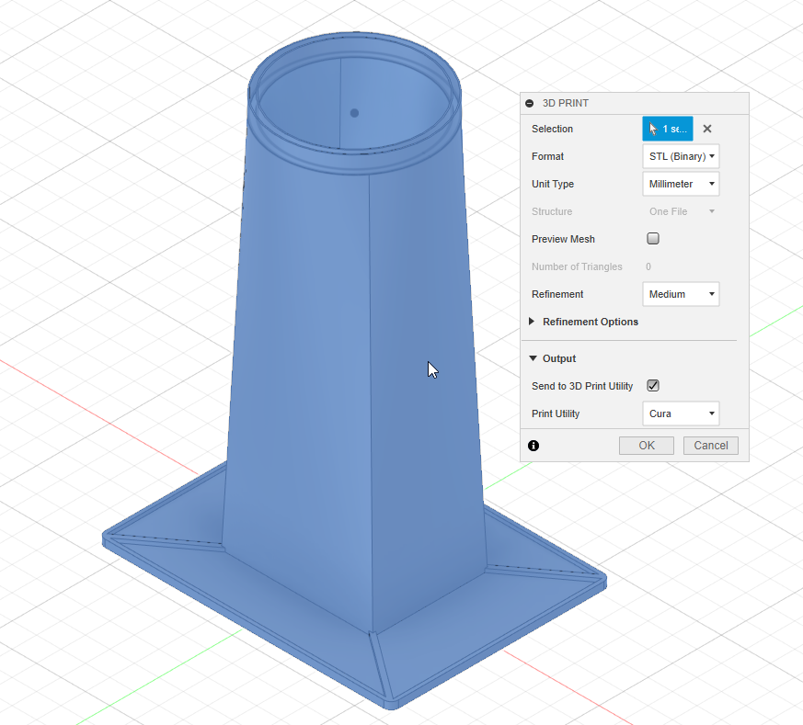
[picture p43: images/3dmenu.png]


* Press `Save` icon to save the project as your own.

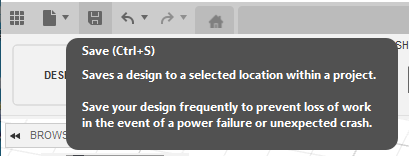
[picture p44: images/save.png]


Now with the bespoke traffic cone model, head back to [the main guide!](README.md#printing-the-cone) (`Printing the cone` section)

## License Note

The **scanning cone** design is under [CC BY 4.0 License](https://creativecommons.org/licenses/by/4.0/deed.en)

You can:

* Share, modify, remix, and redistribute the material, even commercially.
* **AS LONG AS** you give appropriate credit to me (dekuNukem) and [the project page](https://github.com/dekuNukem/traffic-cone-film-scanning).

The sample photos are **NOT** under CC BY 4.0 and are all rights reserved.

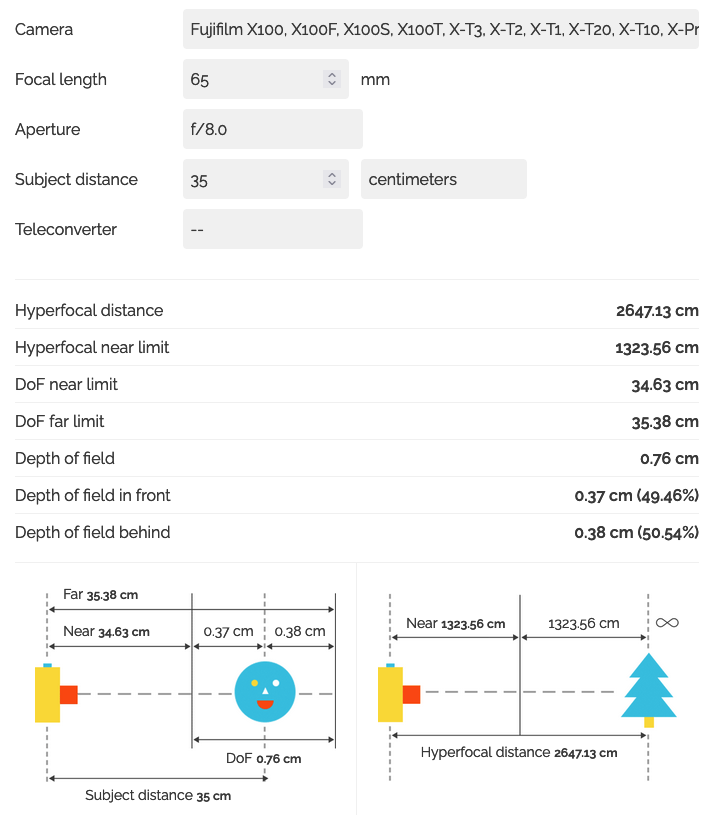
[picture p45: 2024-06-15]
images/dof120.png

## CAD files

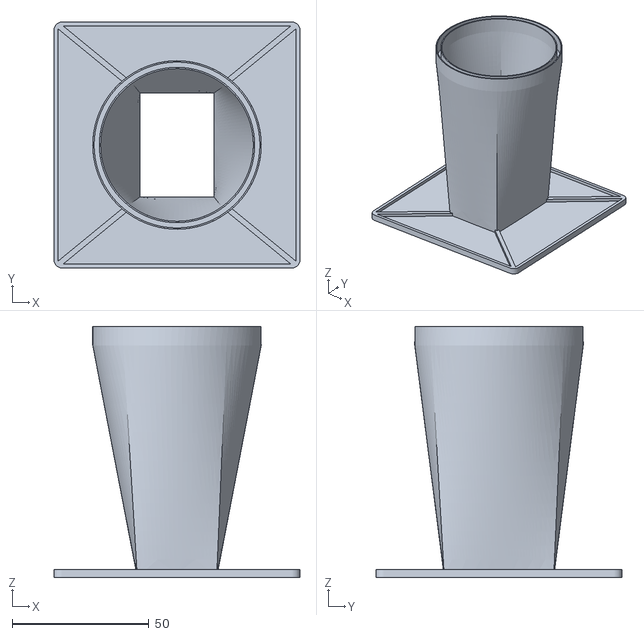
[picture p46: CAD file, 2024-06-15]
3d_models/laowa_7art_35mm_fullframe.stl
90.0 x 90.0 x 92.0

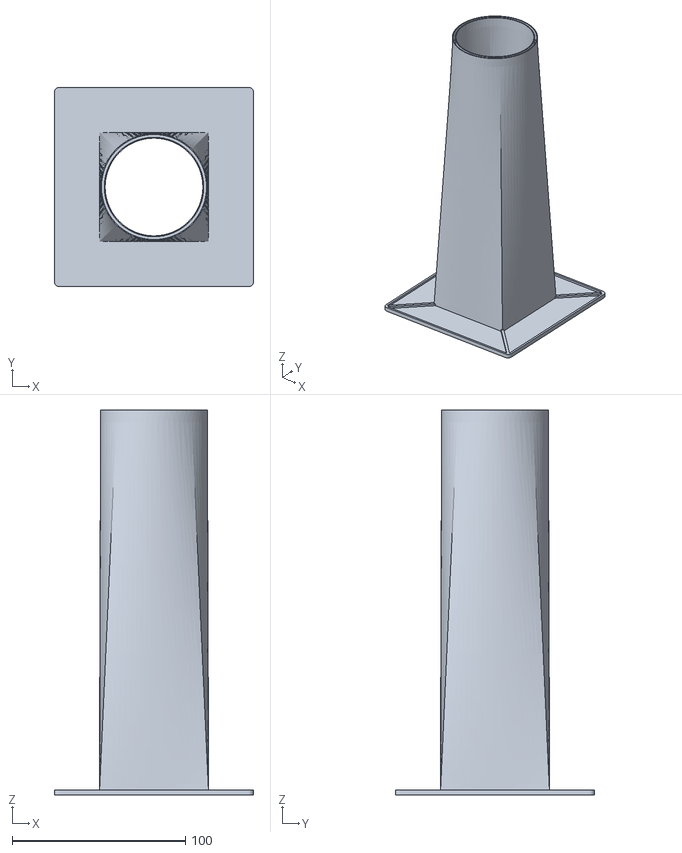
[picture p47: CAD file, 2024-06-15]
3d_models/laowa_7art_6x6.stl
115.0 x 115.0 x 222.0

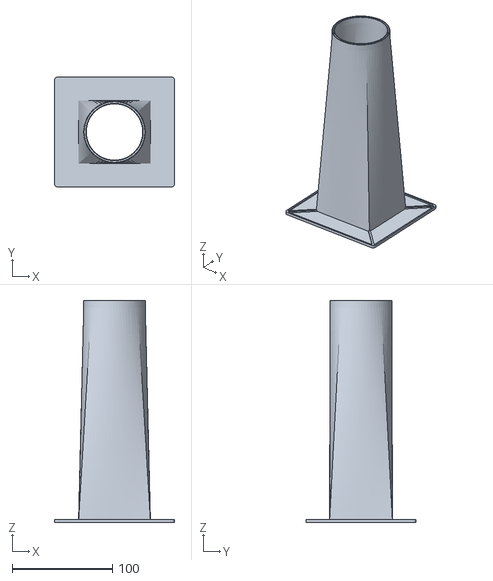
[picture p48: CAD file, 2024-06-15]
3d_models/laowa_7art_6x7.stl
120.0 x 110.0 x 222.0

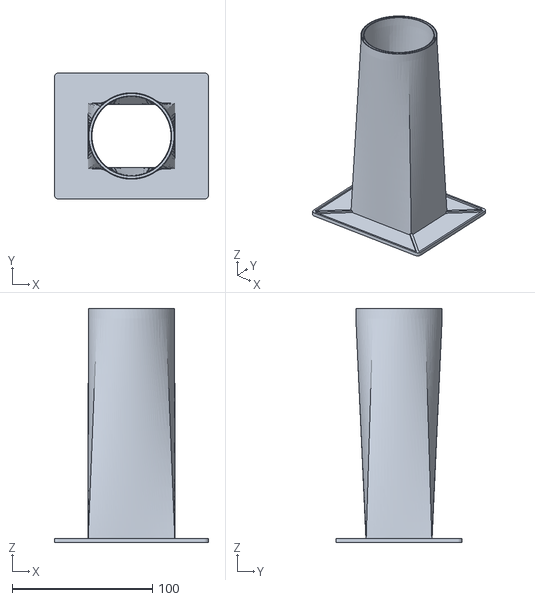
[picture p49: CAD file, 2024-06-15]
3d_models/laowa_7art_645.stl
110.0 x 90.0 x 167.0

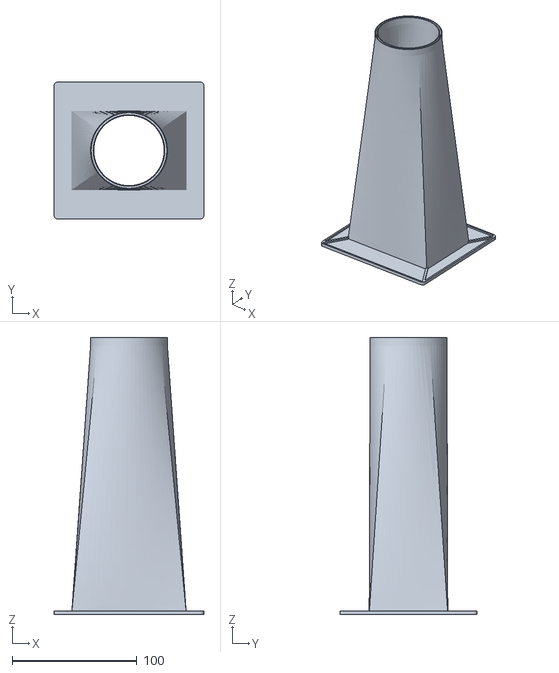
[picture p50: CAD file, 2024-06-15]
3d_models/laowa_7art_6x9.stl
120.0 x 110.0 x 222.0

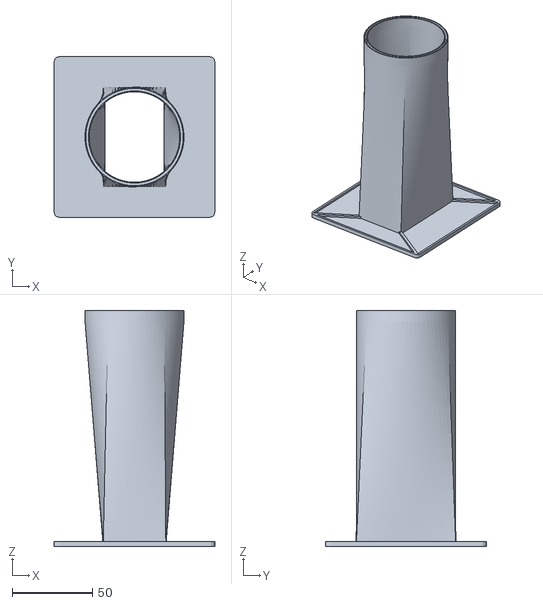
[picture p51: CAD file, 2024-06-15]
3d_models/laowa_7art_35mm_sprocket_6x6.stl
100.0 x 100.0 x 147.0

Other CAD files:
3d_models/cone_template.f3d

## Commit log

2024-06-04 added cone template f3d
    [cone_template_fusion360.f3d]
2024-06-06 updated license
    [cone_template.f3d, cone_template_fusion360.f3d]
2024-06-15 added more sample photos
2024-06-15 added stl files
    [cone_template.f3d, laowa_7art_35mm_fullframe.stl, laowa_7art_35mm_sprocket_6x6.stl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]
